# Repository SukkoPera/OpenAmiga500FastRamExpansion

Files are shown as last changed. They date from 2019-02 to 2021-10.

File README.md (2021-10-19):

# OpenAmiga500FastRamExpansion
OpenAmiga500FastRamExpansion is an Open Hardware 4/8 MB Fast RAM Expansion for the Commodore Amiga 500 Computer.

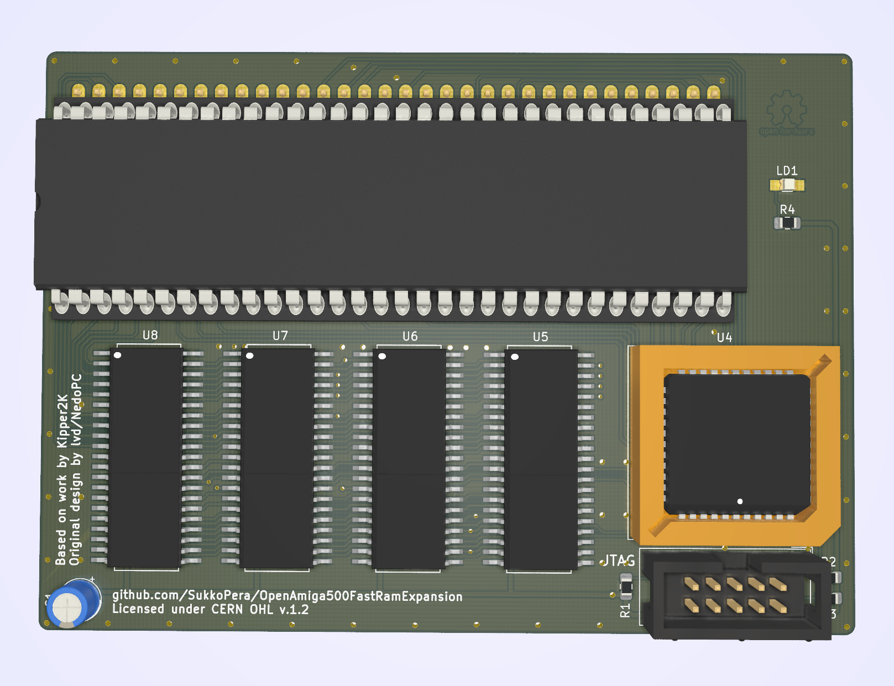
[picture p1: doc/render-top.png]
Board


### Summary
Most low-end Amiga models only came with *Chip RAM*. "Big Box" models allowed for a different type of memory to be installed, known as *Fast RAM*, where *fast* means that it's dedicated to the main processor, so that it doesn't have to compete with the other chips in order to gain access to it (as is the case with Chip RAM). While both Chip and Fast RAM are limited in size, you can have at least a few MB of the latter on all Amigas (usually up to 8), while the former can never exceed 2 MB.

OpenAmiga500FastRamExpansion will allow you to add 4 or 8 MB of Fast RAM to your Amiga 500. This way you will be able to run more applications at once and more quickly. If you combine it with [a chip RAM expansion](http://eab.abime.net/showthread.php?t=85395), you will also be able to run almost all games supported by WHDLoad, pushing your Amiga to its limits.

OpenAmiga500FastRamExpansion is basically a clone of [a RAM expansion produced by Kipper2K a few years ago](http://eab.abime.net/showthread.php?t=64218), based on [an earlier design by lvd/NedoPC](http://lvd.nedopc.com/Projects/a600_8mb/index.html). He has since stopped producing and selling these cards and I thought it was a pity that he didn't open his designs and actually took all of them down, as this card is quite cheap to build and really useful. So I set about recreating it from scratch.

### Memory Compatibility
The required RAM Type is 16 Mbit (1M×16) DRAM in the SOJ-42 package with up to 70-80 ns access time. It is 5v-only DRAM (not SD(!)RAM) often found in old 72-pin SIMMs, EDO chips might work or not. All chips having *8160* in their part number should be OK.

|Model |Maker |Tested |Working |Data Sheet |Notes |
|---|---|:---:|:---:|:---:|---|
|AS4C1M116E5 |Alliance |Yes|Yes| |Tested by @Homer799 |
|GM71C18160 |Hynix/LGS |Yes|Yes|PDF |Tested by lvd in his original project |
|HY5118164B |Hynix |Yes|Yes| |Tested by @Sgw32 |
|KM416C1200AJ |SEC |Yes|Yes| |Reported working by Ronald Baer |
|KM416C1204AJ/BJ|SEC |Yes|Yes|PDF (http://pdf.datasheetcatalog.com/datasheet_pdf/samsung-electronic/KM416C1004BJ-45_to_KM416V1204BT-L7.pdf) |Reported working by screwbreaker |
|MSM5118160 |OKI |Yes|Yes|PDF |Tested by lvd in his original project |
|TMS41860DZ |Texas Instruments |Yes|Yes| |Reported working by Ronald Baer |
|TMS41869DZ |Texas Instruments |No  | | | |
|4218160 |NEC |Yes|Yes| |Reported working by Ronald Baer |
|4218165 |NEC |Yes|Yes|PDF (https://www.datasheetarchive.com/pdf/download.php?id=5f10686e336fc0bb44481c8b0f0340b8d05d8a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) |Tested by SukkoPera |
|VG2618165BJ |Vanguard |Yes|Yes| |Tested by @Csordi |
|NN5118160AJ-60 |NPN |Yes|Yes| |Tested by @RipZ |

RAM chips can either be soldered directly to the board or installed in sockets. While soldering the chips might not be trivial for the unexperienced, sockets for the SOJ-42 package are hard to find and not really easier to solder either, so the choice is up to you.

### Assembly and Installation
Normally it is not necessary to mount all the decoupling capacitors. I usually skip C4, C5, C9, C12, C15 and C18. Maybe C1 can be left out as well if you have a good power supply, your choice. R4 must be chosen according to the particular led you will be using for LD1. Actually you are free to skip LD1 and R4 altogether, if you hate power LEDs.

After everything has been soldered, you will need to program the CPLD. Whenever you do so, **make sure to carefully remove the board from your Amiga, or you might risk damaging it**. You can find the firmware [here](firmware/V2), along with instructions on how to flash it. You can provide power through the pads of C1 if you need to do so.

Make sure to use the [correct firmware version](#Firmware), according to how many chips you soldered on the board! For the 4 MB version, solder U7 and U8 only and use the dedicated firmware.

When assembly is complete, open your A500 and remove the top shield. Carefully remove the CPU (largest chip at bottom left of the board), using a chip extractor or a small flat screwdriver, taking care not to break/bend any pins. Plug it on the board, matching the orientation, and plug the whole board in the CPU socket.

Before reassembling your case, I recommend to run [SysTest/Amiga Test Kit](https://github.com/keirf/Amiga-Stuff). Use the Memory option (<kbd>F1</kbd>), it must show 4/8 MB of Fast RAM. Then start the Memory Test (<kbd>F1</kbd> again) and let it run for 50-100 rounds: if it doesn't find any errors, you are probably good to go. If you get any errors, check your solder joints, starting from actual the RAM chips, as the SOJ package is not very hand-soldering-friendly.

### Firmware
If you are using Kickstart 2.x or higher you should use the latest V2 firmware [here](firmware/V2) noting that it requires an ATF1504AS rather than the older version's ATF1502

If you are using Kickstart 1.3 you will need to use the [V1 Firmware here](firmware/V1)

#### V2 Firmware new features
Thanks to two new features this board is compatible with other autoconfig devices and should no longer cause any conflicts
* Autoconfig snooping - This board will configure itself after every other Autoconfig device
* Autosizing - The firmware will shrink the configured size automatically to make it fit within the remaining free memory pool (8M/4M/2M/1M).

#### V1 Firmware Limitations
The V1 Firmware for OpenAmiga500FastRamExpansion only has a partial implementation of the AutoConfig protocol. This has the following consequences:
- On the A500 it will only work if nothing is connected to the side expansion port (or if whatever is connected does NOT use AutoConfig).
- On the A2000 it will only work if nothing is installed in the Zorro expansion slots (again: or if whatever you installed there does not use AutoConfig).
- On the CDTV it just won't work (since the DMAC uses AutoConfig and is built-in.)

Because of these limitations it is recommended to use the new Firmware where possible, this will allow your board to coexist with other Autoconfig devices.
If you cannot use the V2 firmware for some reason (i.e you use Kickstart 1.3) then the only way to get around these limitations is flashing an alternative firmware on the board which does not use AutoConfig, but then you will have to add the RAM manually in Workbench, using the `addmem` utility. More on this soon.

### License
The OpenAmiga500FastRamExpansion documentation, including the design itself, is copyright &copy; SukkoPera 2019.

OpenAmiga500FastRamExpansion is Open Hardware licensed under the [CERN OHL v. 1.2](http://ohwr.org/cernohl).

You may redistribute and modify this documentation under the terms of the CERN OHL v.1.2. This documentation is distributed *as is* and WITHOUT ANY EXPRESS OR IMPLIED WARRANTIES whatsoever with respect to its functionality, operability or use, including, without limitation, any implied warranties OF MERCHANTABILITY, SATISFACTORY QUALITY, FITNESS FOR A PARTICULAR PURPOSE or infringement. We expressly disclaim any liability whatsoever for any direct, indirect, consequential, incidental or special damages, including, without limitation, lost revenues, lost profits, losses resulting from business interruption or loss of data, regardless of the form of action or legal theory under which the liability may be asserted, even if advised of the possibility or likelihood of such damages.

A copy of the full license is included in file [LICENSE.pdf](LICENSE.pdf), please refer to it for applicable conditions. In order to properly deal with its terms, please see file [LICENSE_HOWTO.pdf](LICENSE_HOWTO.pdf).

The contact points for information about manufactured Products (see section 4.2) are listed in file [PRODUCT.md](PRODUCT.md).

Any modifications made by Licensees (see section 3.4.b) shall be recorded in file [CHANGES.md](CHANGES.md).

The Documentation Location of the original project is https://github.com/SukkoPera/OpenAmiga500FastRamExpansion/.

### Support the Project
Since the project is open you are free to get the PCBs made by your preferred manufacturer, however in case you want to support the development, you can order them from PCBWay through this link:

PCB from PCBWay (https://www.pcbway.com/project/shareproject/OpenAmiga500FastRamExpansion_V1.html)

You get my gratitude and cheap, professionally-made and good quality PCBs, I get some credit that will help with this and [other projects](https://www.pcbway.com/project/member/shareproject/?bmbid=41100). You won't even have to worry about the various PCB options, it's all pre-configured for you!

Also, if you still have to register to that site, [you can use this link](https://www.pcbway.com/setinvite.aspx?inviteid=41100) to get some bonus initial credit (and yield me some more).

Again, if you want to use another manufacturer, feel free to, don't feel obligated :). But then you can buy me a coffee if you want:

<a href='https://ko-fi.com/L3L0U18L' target='_blank'>Buy Me a Coffee at ko-fi.com</a>

### Get Help
If you need help or have questions, you can join [the official Telegram group](https://t.me/joinchat/HUHdWBC9J9JnYIrvTYfZmg).

### Thanks
- lvd for the initial design and the support he gave me during development
- Kipper2K for making his boards
- majinga for helping with the testing

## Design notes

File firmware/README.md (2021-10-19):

# Firmware
Before installing the board into your Amiga, you will need to program the CPLD chip.

The firmware is the same as the original project by lvd. It has been copied here for convenience, but it is unmodified.

The firmware was originally developed for Altera `EPM7032SLC44` CPLDs.

Atmel/Microchip makes compatible devices under the `ATF1502` series, so the `ATF1502AS-10JC44` can be used as an alternative, which is easier to find nowadays (-10J*U*44 is fine as well).

## Flashing the firmware

### Altera EPM7032SLC44/EPM7064SLC44
You will need to load the `.POF` file in `quartus_pgm` and flash it using one of the cheap USB Blaster programmer clones you can find everywhere.

*NOTE: One user recommends NOT to use the auto-detect button as it will add two ICs to the window. Just select the USB Blaster hardware and load the .POF file (make sure to check only Program/Configure + Verify!). Then hit the Start button to flash.*

### Atmel/Microchip ATF1502AS-10JC44/ATF1504AS-10JC44 (Official way)
You can program the .JED file using the [ATDH1150USB](https://www.microchip.com/DevelopmentTools/ProductDetails/ATDH1150USB) programmer.

### Atmel/Microchip ATF1502AS-10JC44/ATF1504AS-10JC44 (Cheaper and hackish way)
These days you will only find the ATF1502AS-10JC44 (or -10JU44) on the market, but, if you read the above, you will know that you will need to buy a >50€ programmer to program it, which doesn't sound reasonable, as this will most likely only need to be done once. Besides, all the tools mentioned above are Windows-only so if you are a Linux user like me, you're pretty screwed. Luckily, there is a solution that allows flashing the Atmel chip with the cheap USB Blaster clones. I have developed and tested it under Linux, but it should also work on Windows and OS X.

First of all you need to power the board. JTAG programmers are not supposed to provide power, hence you need to do so separately. The board does not have a dedicated power connector, but you can use the pads of C1 (which I don't recommend installing, unless you have stability issues) or pins 2 (GND) and 4 (VCC) of the IDC connector. The board needs 5V, I usually take those from an Arduino board but feel free to use whatever suits you.

On the software side, you will need [UrJTAG](http://urjtag.sourceforge.net). I have only tested version 2018.09, others might work or not. I am not sure this version is readily available in binary format, so you might have to compile it from sources.

You will also need to get the [BSDL (Boundary Scan Description Language) files for the 1502 CPLDs](http://ww1.microchip.com/downloads/en/DeviceDoc/1502bsdl.zip). Download the zip file, uncompress it anywhere you like and take note of the path, you will need it later.

Finally, you will need the firmware in SVF format, available in this folder. Use either `4mb.svf` or `8mb.svf` according to how you assembled your board.

Now you are ready for the actual flashing, so connect your USB Blaster to the IDC connector on the board and plug it into an USB port on your PC. Then run urjtag as follows:

```
sukko@shockwave firmware $ sudo jtag

UrJTAG 2018.09 #
Copyright (C) 2002, 2003 ETC s.r.o.
Copyright (C) 2007, 2008, 2009 Kolja Waschk and the respective authors

UrJTAG is free software, covered by the GNU General Public License, and you are
welcome to change it and/or distribute copies of it under certain conditions.
There is absolutely no warranty for UrJTAG.

warning: UrJTAG may damage your hardware!
Type "quit" to exit, "help" for help.

jtag> cable UsbBlaster
Connected to libftdi driver.
```

This means that your USB Blaster was detected correctly. Let's load the BSDL files, this is where you will need to use the path you took note of at the beginning:
```
jtag> bsdl path <path>
jtag>
```

Now we can scan the JTAG chain:
```
jtag> detect
IR length: 10
Chain length: 1
Device Id: 00000001010100000010000000111111 (0x0150203F)
  Filename:     bsdl/1502AS_A44.bsd
```

This means that the CPLD was found and it is ready to be programmed. If you get no output at this step, try disconnecting and reconnecting the USB Blaster or power to the board. If the chip gets detected but it is reported as unsupported, check that you downloaded the correct BSDL files. Then start the flashing:
```
jtag> svf 8mb.svf progress stop
warning: unimplemented mode 'ABSENT' for TRST
detail: Parsing   3660/3668 ( 99%)detail:
detail: Scanned device output matched expected TDO values.
```

If you get the above output, the flashing was successful and you can start using your board. If instead you get something like:
```
jtag> svf 8mb.svf
warning: unimplemented mode 'ABSENT' for TRST
Error svf: mismatch at position 64 for TDO
 in input file between line 2196 col 1 and line 2198 col 32
```

Then there was an error during the flashing, check your wiring, power and try again.

#### USB Blaster Clones
You are recommended to get **a full-size Altera USB Blaster clone**, i.e. one of these:

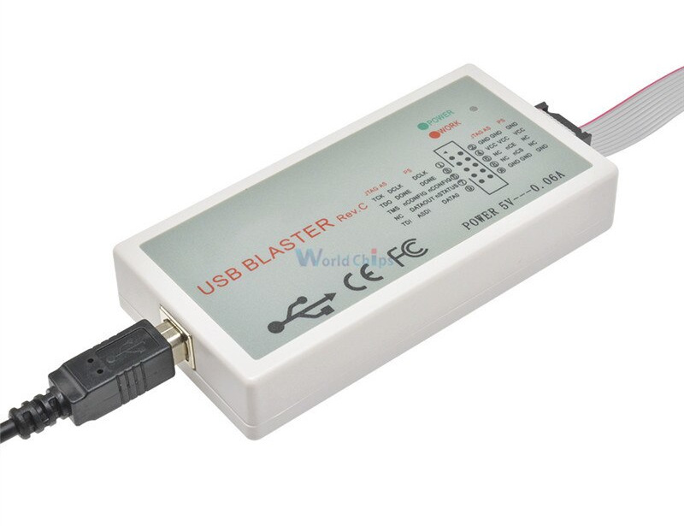
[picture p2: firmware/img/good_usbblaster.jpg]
Full-Size


Note the *Rev.C*: I'm not sure if it is crucial, but the one I have says so and is working very well.

Do **NOT** buy this:

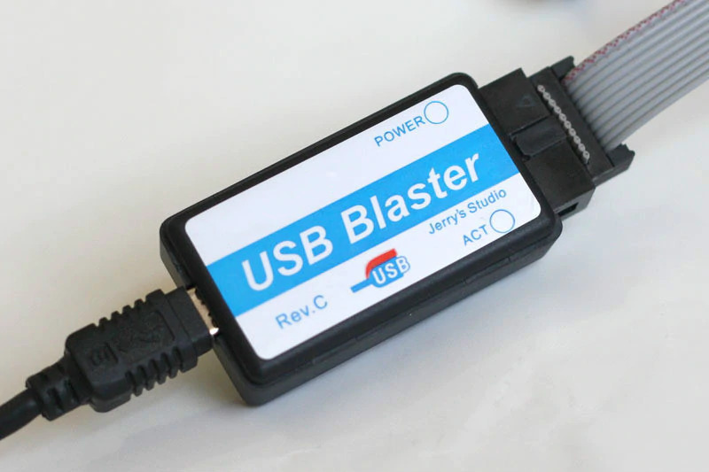
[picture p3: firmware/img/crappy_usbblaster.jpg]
Smaller


It does not work correctly, as it always hangs between 47% and 49% of the flashing process.

### Atmel/Microchip ATF1502AS-10JC44 (Through the Parallel port)

As an alternative, if you have an old computer with LPT1 and some version of Windows, you can build [the cable mentioned here](https://github.com/MattisLind/82S100replacement) and use it with [Microchip's ATMISP tool](https://www.microchip.com/design-centers/programmable-logic/spld-cpld/tools/software/atmisp).

## Windows considerations
I have managed to build a Windows binary of UrJTAG with only the minimum options needed to program these CPLDs through a USB Blaster. It was tested by a couple of users and seemed to be working fine. A user even automated the procedure, so now you can just download [the UrJTAG.zip file from the windows folder](windows/UrJTAG.zip), unzip it and double click on the `runme.bat` script (with the programmer and board already connected to your PC): this should guide you through the whole flashing process.

I hope this works for you, but please note that **it is unsupported**, as I have no computers running Windows.

## Tinkering with the firmware
The firmware was developed with Quartus 7.2, somewhat totally old and outdated, but I never got any problems with it. I DO NOT recommend using Quartus 6.x as I caught it generating wrong designs (in a way, nothing is working and when you swap to Quartus 7.2 not touching you project, everything is working back).

If you want to move to something newer, it seems that Quartus 10.x and 11.x are still supporting EPM7000S chips. Starting from Quartus 12.x there's no more support for that devices.

### POF => JED
Quartus will produce a .POF file. This can be converted to a .JED file for Atmel devices through [Microchip's POF2JED utility](https://www.microchip.com/design-centers/programmable-logic/spld-cpld/tools/software/pof2jed), which is Windows-only unfortunately.

### JED => SVF
An SVF file can be produced using [ATMISP](https://www.microchip.com/design-centers/programmable-logic/spld-cpld/tools/software/atmisp), which is also Windows-only.

### Used chips from China
The chips can be pre-used if you bought your ATF1502AS from China. Sometimes JTAG interface is disabled on them, preventing normal JTAG operations.

To enable JTAG, connect +12V power through a 2.2kOhm resistor to pin 7 on the 68000 CPU connector. Afterwards flash the `atf1502as_erase.svf` file to the CLPD. Then you can follow the normal programming procedures.

## Thanks
- *lvd* for providing most of the above information and helping me come up with the Linux flashing procedure.
- *majinga* and *go0se* for testing and helping improve this procedure.
- EAB forum user *katarakt* for the note on Quartus.
- Szymon Roslowski and Graham P. for testing and improving the Windows package.

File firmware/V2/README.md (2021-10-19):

# GottaGoFast firmware for SukkoPera's OpenAmiga500FastRam expansion

This is a port of the GottaGoFastRAM firmware for the OpenAmiga500FastRam Expansion.  
It adds better Autoconfig support, making the board play nicely with other Autoconfig devices.

## Requirements

* Requires Kickstart 2 or higher.
* This firmware is only compatible with either the ATF1504AS or EPM7064S CPLDs, the ATF1502 specced for this board originally does not have enough resources for this firmware.

## Usage

Follow the programming steps [here](../README.md)

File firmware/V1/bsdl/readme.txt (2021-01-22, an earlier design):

******************************************************************************
*           BSDL files for ATF1502AS/ASL/ASV in all package types            *
******************************************************************************

1502AS_A44.bsd  - BSDL file for ATF1502AS/ASL in 44-pin TQFP package type.

1502AS_J44.bsd  - BSDL file for ATF1502AS/ASL in 44-pin PLCC package type.

1502ASV_A44.bsd - BSDL file for ATF1502ASV in 44-pin TQFP package type.

1502ASV_J44.bsd - BSDL file for ATF1502ASV in 44-pin PLCC package type.

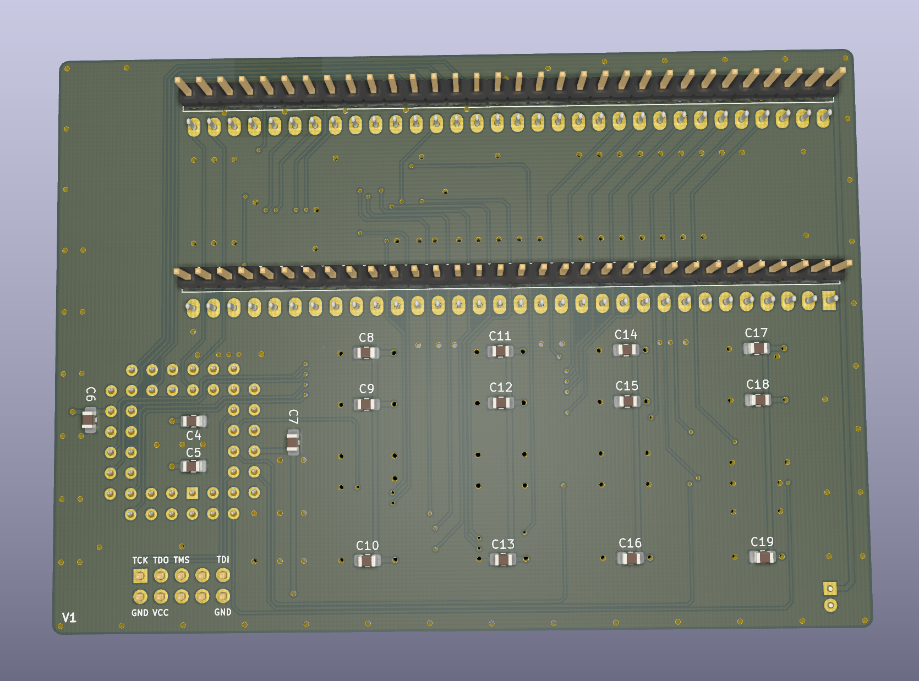
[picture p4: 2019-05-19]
doc/render-bottom.png

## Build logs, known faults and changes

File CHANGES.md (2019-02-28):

## CHANGES

Any modifications to the OpenAmiga500FastRamExpansion design and documentation made by any Licensee MUST be noted in this file, as per *section 3.4.b* of the [license](LICENSE.pdf).

### (Date) - (Author)
(Description)

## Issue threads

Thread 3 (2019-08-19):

Fix skippable cap numbers

SukkoPera, 2019-08-19:
Brought over from A600 expansion, they do not seem correct.

(Thanks @screwbreaker)

SukkoPera, 2019-08-19:
Not applicable.

Closed 2019-08-19.

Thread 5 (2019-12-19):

New memory compatibly testing

Homer799, 2019-12-19:
AS4C1M116E5 - Alliance - confirmed working
IS41C16105 - TBC
GM71C18163 - TBC
TC5118160AJ - TBC

Csordi, 2019-12-28:
I used VG2618165BJ - Vanguard Microelectronics and this RAMs is also working fine.

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

RipZ, 2020-11-15:
NPN NN5118160AJ-60 - Worked
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

Sgw32, 2021-01-10:
HY5118164B from old RAMs - working!

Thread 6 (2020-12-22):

TF534 compatibility.

andreacampanella, 2020-12-22:
I have been using the card for an year and I recently got a TF534. I can see the memory in Workbench but ram test comes back with some errors.

Is there any known problem with it?

It's 8MB

SukkoPera, 2020-12-23:
To be honest, I don't know. I think it is *supposed* to work with the TF534, but I don't have one and can't say for sure.

I'm leaving this open for anyone to contribute.

andreacampanella, 2020-12-24:
I think my board it's defective, I have to investigate more.

This is the error but I can't really understand how to interpret it.
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

SukkoPera, 2020-12-24:
I had lot of similar errors while testing mem68k with my TF530. Never managed to fix them.

I'm sorry but I really can't help more :(.

andreacampanella, 2020-12-25:
Weird, it seems something isolated to the 500+ I'm using, the other 500 it's kinda fine.

Need more testing, seems harware related.

SukkoPera, 2020-12-25:
Maybe a wonky socket?

andreacampanella, 2020-12-25:
I don't really understand, I just removed all the chip ram and I'm about to test it.

andreacampanella, 2021-01-04:
yeah, something is up with my 500+, works with my 500.

SukkoPera, 2021-01-04:
OK, closing then.

Closed 2021-01-04.

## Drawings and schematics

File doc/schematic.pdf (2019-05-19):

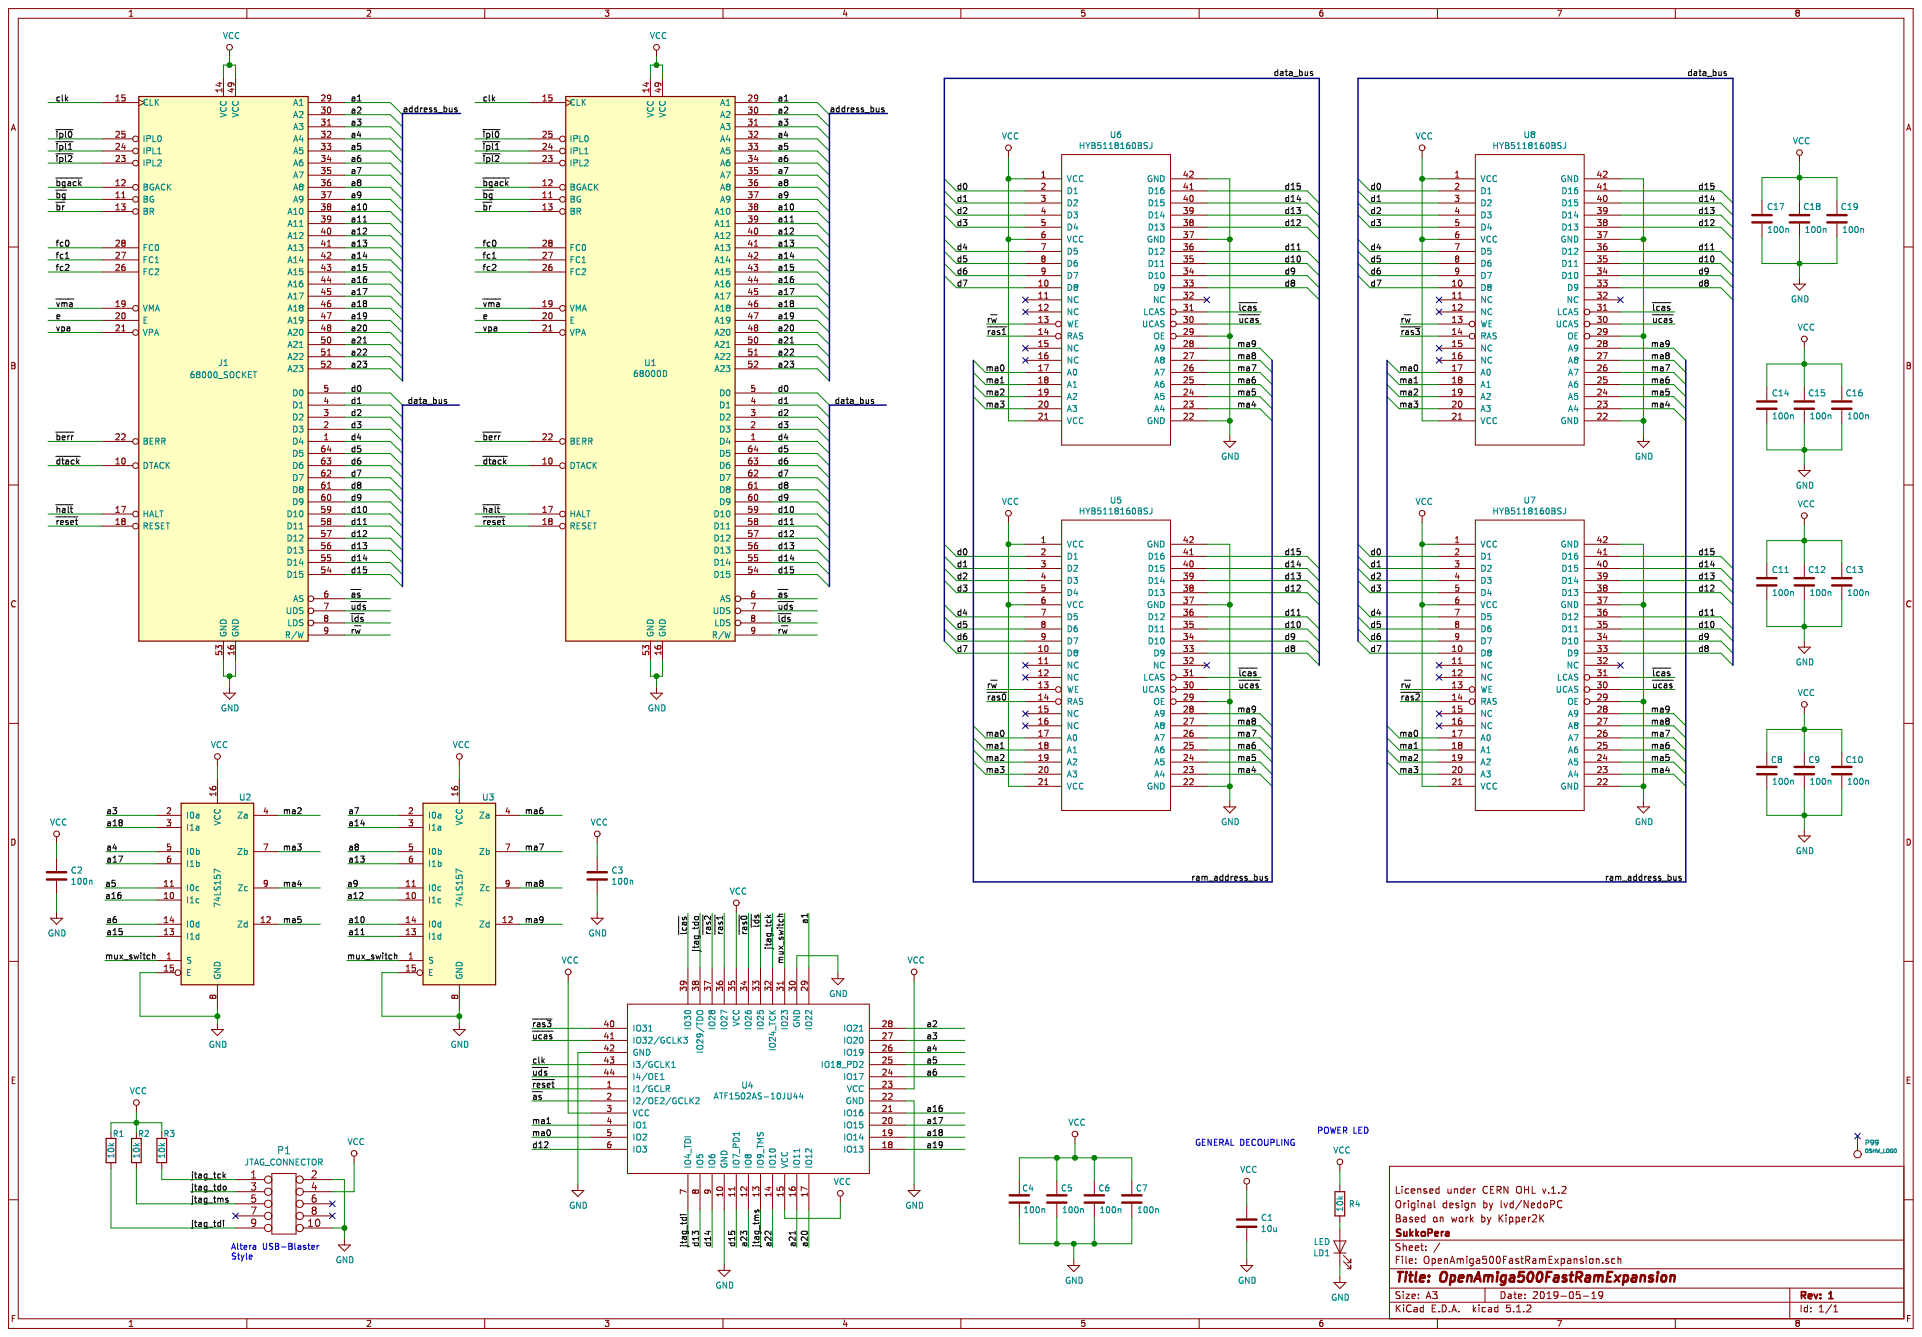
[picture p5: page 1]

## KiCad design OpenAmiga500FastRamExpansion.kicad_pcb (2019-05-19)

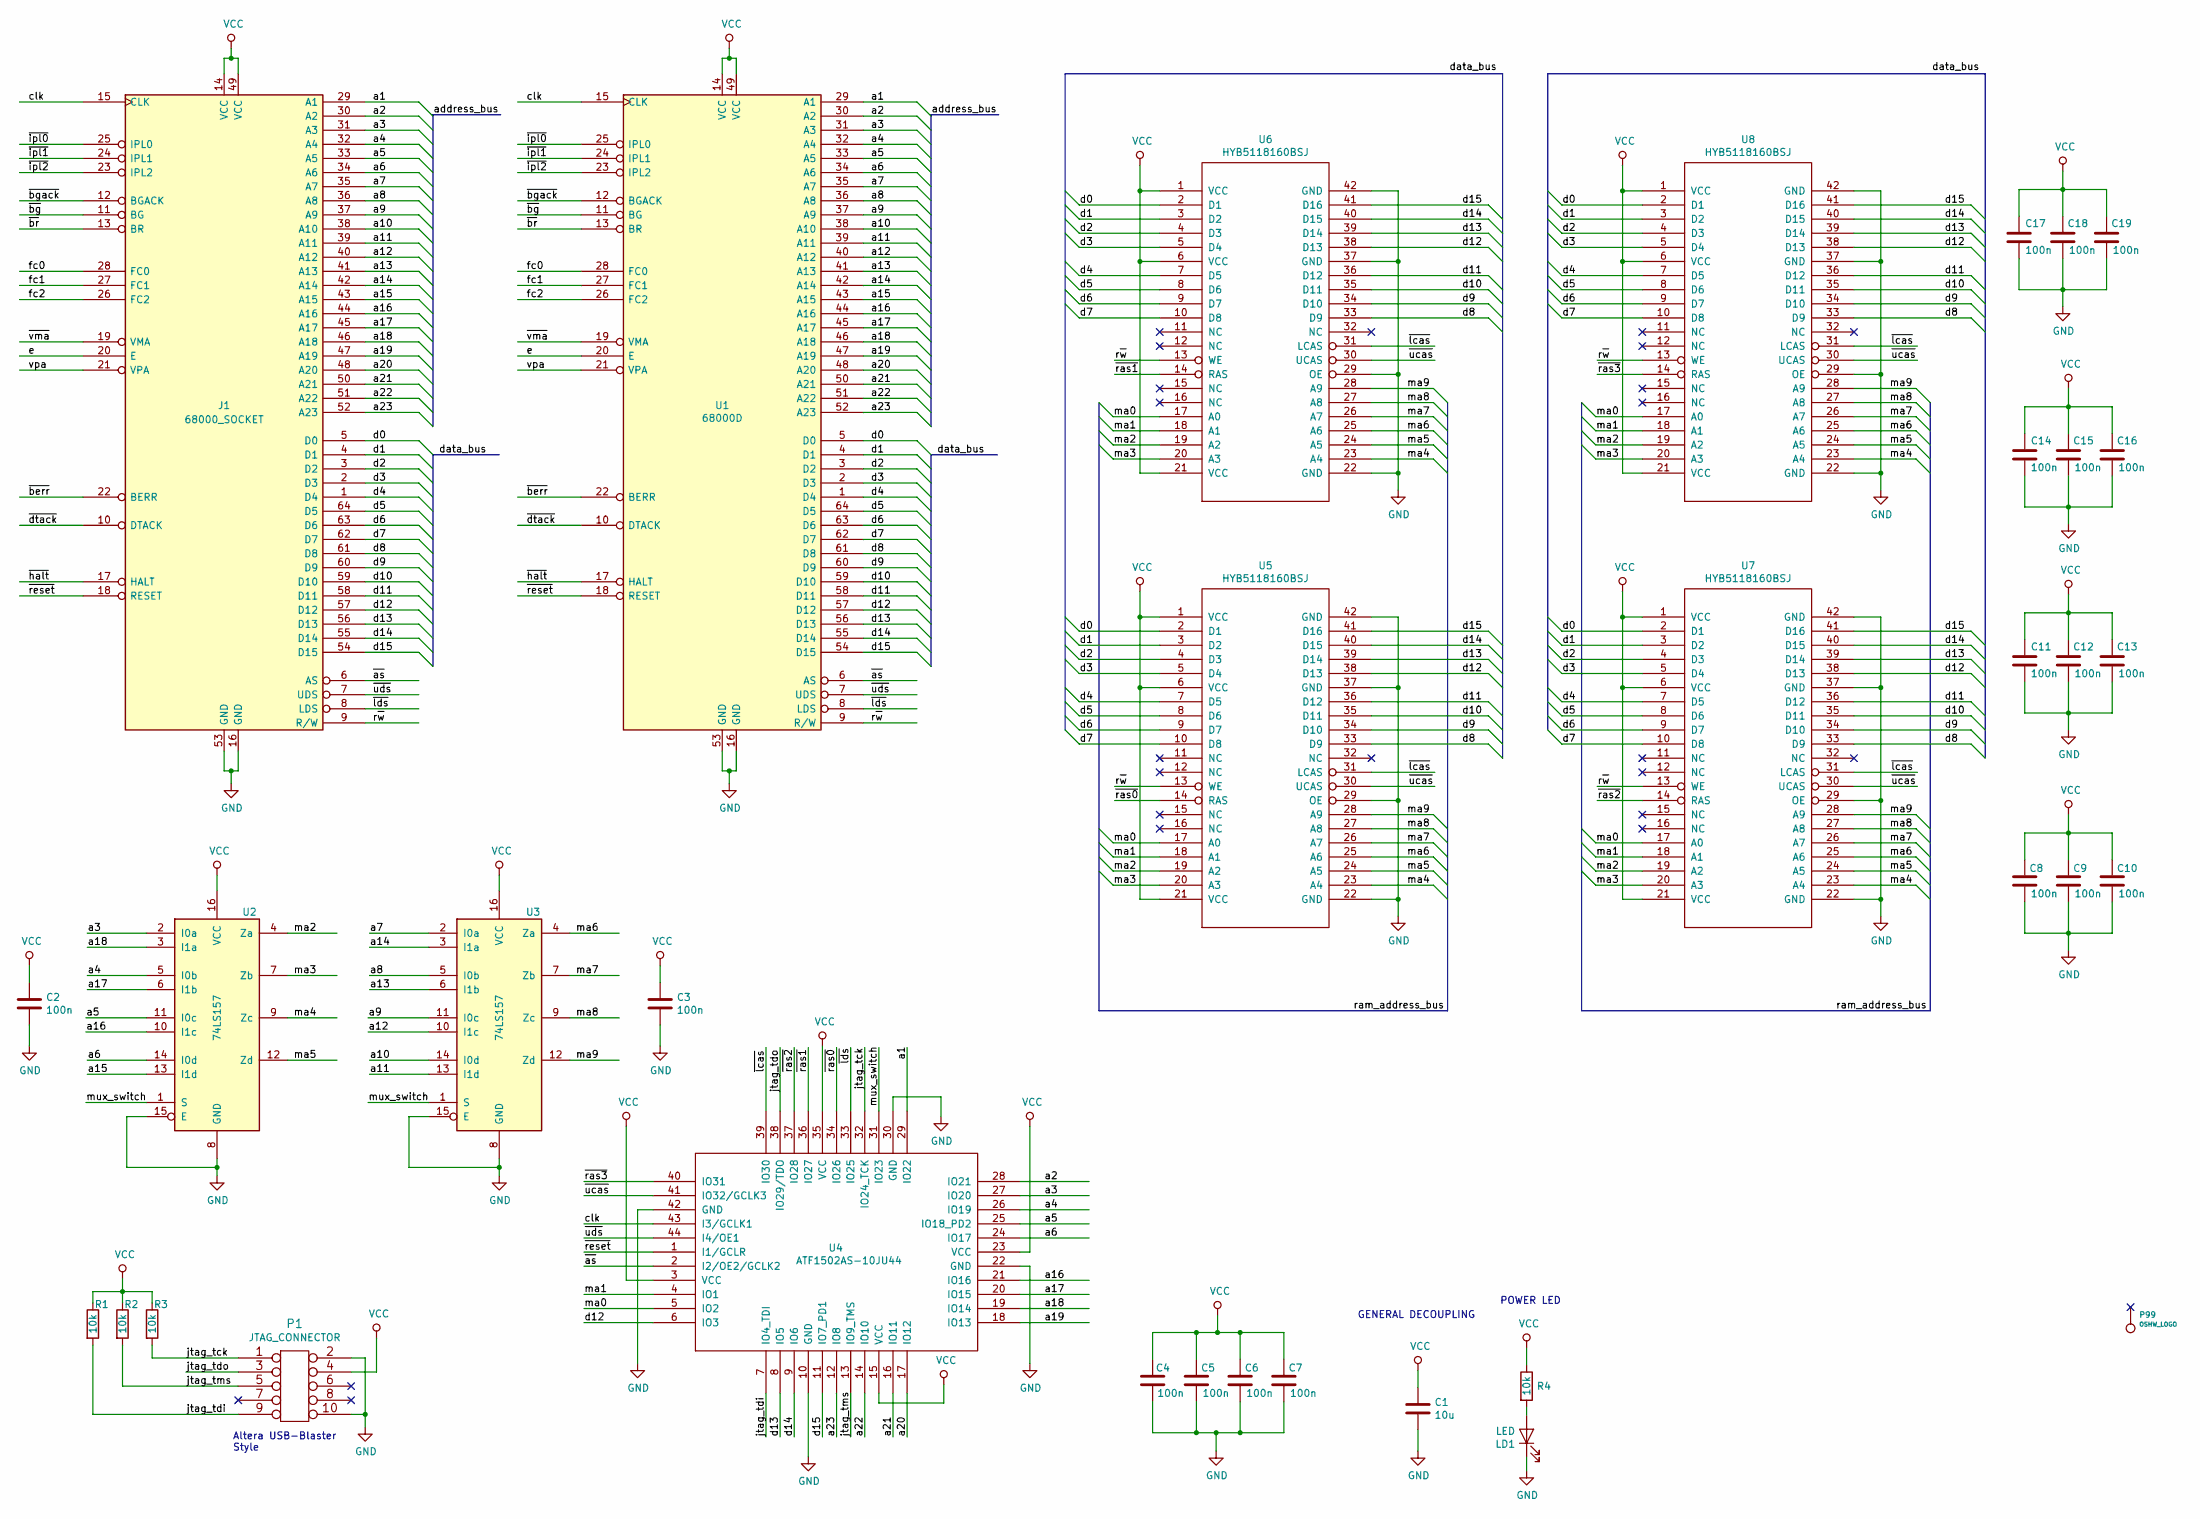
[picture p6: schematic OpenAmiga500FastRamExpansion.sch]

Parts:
C1: 10u; CP_Radial_D5.0mm_P2.00mm
C2, C3, C4, C5, C6, C7, C8, C9, C10, C11, C12, C13, C14, C15, C16, C17, C18, C19: 100n; C_0805_2012Metric_Pad1.15x1.40mm_HandSolder
J1: 68000_SOCKET; DIP-64_W22.86mm_Socket_LongPads_Socket
LD1: LED; LED_0805_HandSoldering_ModSilkS
P1: JTAG_CONNECTOR; IDC-Header_2x05_P2.54mm_Vertical
P99: OSHW_LOGO; OSHW-Logo2_7.3x6mm_Copper
R1, R2, R3, R4: 10k; R_0805_2012Metric_Pad1.15x1.40mm_HandSolder
U1: 68000D; DIP-64_W22.86mm_Socket_LongPads_IC
U2, U3: 74LS157; SOIC-16_3.9x9.9mm_P1.27mm
U4: ATF1502AS-10JU44; PLCC-44_THT-Socket
U5, U6, U7, U8: HYB5118160BSJ; SOJ-42-LongPads

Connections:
/a1: J1.29 (A1), U1.29 (A1), U4.29 (IO22)
/a2: J1.30 (A2), U1.30 (A2), U4.28 (IO21)
/a3: J1.31 (A3), U1.31 (A3), U2.2 (I0a), U4.27 (IO20)
/a4: J1.32 (A4), U1.32 (A4), U2.5 (I0b), U4.26 (IO19)
/a5: J1.33 (A5), U1.33 (A5), U2.11 (I0c), U4.25 (IO18_PD2)
/a6: J1.34 (A6), U1.34 (A6), U2.14 (I0d), U4.24 (IO17)
/a7: J1.35 (A7), U1.35 (A7), U3.2 (I0a)
/a8: J1.36 (A8), U1.36 (A8), U3.5 (I0b)
/a9: J1.37 (A9), U1.37 (A9), U3.11 (I0c)
/a10: J1.38 (A10), U1.38 (A10), U3.14 (I0d)
/a11: J1.39 (A11), U1.39 (A11), U3.13 (I1d)
/a12: J1.40 (A12), U1.40 (A12), U3.10 (I1c)
/a13: J1.41 (A13), U1.41 (A13), U3.6 (I1b)
/a14: J1.42 (A14), U1.42 (A14), U3.3 (I1a)
/a15: J1.43 (A15), U1.43 (A15), U2.13 (I1d)
/a16: J1.44 (A16), U1.44 (A16), U2.10 (I1c), U4.21 (IO16)
/a17: J1.45 (A17), U1.45 (A17), U2.6 (I1b), U4.20 (IO15)
/a18: J1.46 (A18), U1.46 (A18), U2.3 (I1a), U4.19 (IO14)
/a19: J1.47 (A19), U1.47 (A19), U4.18 (IO13)
/a20: J1.48 (A20), U1.48 (A20), U4.17 (IO12)
/a21: J1.50 (A21), U1.50 (A21), U4.16 (IO11)
/a22: J1.51 (A22), U1.51 (A22), U4.14 (IO10)
/a23: J1.52 (A23), U1.52 (A23), U4.12 (IO8)
/clk: J1.15 (CLK), U1.15 (CLK), U4.43 (I3/GCLK1)
/d0: J1.5 (D0), U1.5 (D0), U5.2 (D1), U6.2 (D1), U7.2 (D1), U8.2 (D1)
/d1: J1.4 (D1), U1.4 (D1), U5.3 (D2), U6.3 (D2), U7.3 (D2), U8.3 (D2)
/d2: J1.3 (D2), U1.3 (D2), U5.4 (D3), U6.4 (D3), U7.4 (D3), U8.4 (D3)
/d3: J1.2 (D3), U1.2 (D3), U5.5 (D4), U6.5 (D4), U7.5 (D4), U8.5 (D4)
/d4: J1.1 (D4), U1.1 (D4), U5.7 (D5), U6.7 (D5), U7.7 (D5), U8.7 (D5)
/d5: J1.64 (D5), U1.64 (D5), U5.8 (D6), U6.8 (D6), U7.8 (D6), U8.8 (D6)
/d6: J1.63 (D6), U1.63 (D6), U5.9 (D7), U6.9 (D7), U7.9 (D7), U8.9 (D7)
/d7: J1.62 (D7), U1.62 (D7), U5.10 (D8), U6.10 (D8), U7.10 (D8), U8.10 (D8)
/d8: J1.61 (D8), U1.61 (D8), U5.33 (D9), U6.33 (D9), U7.33 (D9), U8.33 (D9)
/d9: J1.60 (D9), U1.60 (D9), U5.34 (D10), U6.34 (D10), U7.34 (D10), U8.34 (D10)
/d10: J1.59 (D10), U1.59 (D10), U5.35 (D11), U6.35 (D11), U7.35 (D11), U8.35 (D11)
/d11: J1.58 (D11), U1.58 (D11), U5.36 (D12), U6.36 (D12), U7.36 (D12), U8.36 (D12)
/d12: J1.57 (D12), U1.57 (D12), U4.6 (IO3), U5.38 (D13), U6.38 (D13), U7.38 (D13), U8.38 (D13)
/d13: J1.56 (D13), U1.56 (D13), U4.8 (IO5), U5.39 (D14), U6.39 (D14), U7.39 (D14), U8.39 (D14)
/d14: J1.55 (D14), U1.55 (D14), U4.9 (IO6), U5.40 (D15), U6.40 (D15), U7.40 (D15), U8.40 (D15)
/d15: J1.54 (D15), U1.54 (D15), U4.11 (IO7_PD1), U5.41 (D16), U6.41 (D16), U7.41 (D16), U8.41 (D16)
/e: J1.20 (E), U1.20 (E)
/fc0: J1.28 (FC0), U1.28 (FC0)
/fc1: J1.27 (FC1), U1.27 (FC1)
/fc2: J1.26 (FC2), U1.26 (FC2)
/jtag_tck: P1.1, R3.2, U4.32 (IO24_TCK)
/jtag_tdi: P1.9, R1.2, U4.7 (IO4_TDI)
/jtag_tdo: P1.3, U4.38 (IO29/TDO)
/jtag_tms: P1.5, R2.2, U4.13 (IO9_TMS)
/ma0: U4.5 (IO2), U5.17 (A0), U6.17 (A0), U7.17 (A0), U8.17 (A0)
/ma1: U4.4 (IO1), U5.18 (A1), U6.18 (A1), U7.18 (A1), U8.18 (A1)
/ma2: U2.4 (Za), U5.19 (A2), U6.19 (A2), U7.19 (A2), U8.19 (A2)
/ma3: U2.7 (Zb), U5.20 (A3), U6.20 (A3), U7.20 (A3), U8.20 (A3)
/ma4: U2.9 (Zc), U5.23 (A4), U6.23 (A4), U7.23 (A4), U8.23 (A4)
/ma5: U2.12 (Zd), U5.24 (A5), U6.24 (A5), U7.24 (A5), U8.24 (A5)
/ma6: U3.4 (Za), U5.25 (A6), U6.25 (A6), U7.25 (A6), U8.25 (A6)
/ma7: U3.7 (Zb), U5.26 (A7), U6.26 (A7), U7.26 (A7), U8.26 (A7)
/ma8: U3.9 (Zc), U5.27 (A8), U6.27 (A8), U7.27 (A8), U8.27 (A8)
/ma9: U3.12 (Zd), U5.28 (A9), U6.28 (A9), U7.28 (A9), U8.28 (A9)
/mux_switch: U2.1 (S), U3.1 (S), U4.31 (IO23)
/r~w: J1.9 (R/W), U1.9 (R/W), U5.13 (WE), U6.13 (WE), U7.13 (WE), U8.13 (WE)
/vpa: J1.21 (VPA), U1.21 (VPA)
/~as: J1.6 (AS), U1.6 (AS), U4.2 (I2/OE2/GCLK2)
/~berr: J1.22 (BERR), U1.22 (BERR)
/~bg: J1.11 (BG), U1.11 (BG)
/~bgack: J1.12 (BGACK), U1.12 (BGACK)
/~br: J1.13 (BR), U1.13 (BR)
/~dtack: J1.10 (DTACK), U1.10 (DTACK)
/~halt: J1.17 (HALT), U1.17 (HALT)
/~ipl0: J1.25 (IPL0), U1.25 (IPL0)
/~ipl1: J1.24 (IPL1), U1.24 (IPL1)
/~ipl2: J1.23 (IPL2), U1.23 (IPL2)
/~lcas: U4.39 (IO30), U5.31 (LCAS), U6.31 (LCAS), U7.31 (LCAS), U8.31 (LCAS)
/~lds: J1.8 (LDS), U1.8 (LDS), U4.33 (IO25)
/~ras0: U4.34 (IO26), U5.14 (RAS)
/~ras1: U4.36 (IO27), U6.14 (RAS)
/~ras2: U4.37 (IO28), U7.14 (RAS)
/~ras3: U4.40 (IO31), U8.14 (RAS)
/~reset: J1.18 (RESET), U1.18 (RESET), U4.1 (I1/GCLR)
/~ucas: U4.41 (IO32/GCLK3), U5.30 (UCAS), U6.30 (UCAS), U7.30 (UCAS), U8.30 (UCAS)
/~uds: J1.7 (UDS), U1.7 (UDS), U4.44 (I4/OE1)
/~vma: J1.19 (VMA), U1.19 (VMA)
GND: C1.2, C2.2, C3.2, C4.2, C5.2, C6.2, C7.2, C8.2, C9.2, C10.2, C11.2, C12.2, C13.2, C14.2, C15.2, C16.2, C17.2, C18.2, C19.2, J1.16 (GND), J1.53 (GND), LD1.1 (K), P1.2, P1.10, U1.16 (GND), U1.53 (GND), U2.8 (GND), U2.15 (E), U3.8 (GND), U3.15 (E), U4.10 (GND), U4.22 (GND), U4.30 (GND), U4.42 (GND), U5.22 (GND), U5.29 (OE), U5.37 (GND), U5.42 (GND), U6.22 (GND), U6.29 (OE), U6.37 (GND), U6.42 (GND), U7.22 (GND), U7.29 (OE), U7.37 (GND), U7.42 (GND), U8.22 (GND), U8.29 (OE), U8.37 (GND), U8.42 (GND)
unnamed: LD1.2 (A), R4.2
VCC: C1.1, C2.1, C3.1, C4.1, C5.1, C6.1, C7.1, C8.1, C9.1, C10.1, C11.1, C12.1, C13.1, C14.1, C15.1, C16.1, C17.1, C18.1, C19.1, J1.14 (VCC), J1.49 (VCC), P1.4, R1.1, R2.1, R3.1, R4.1, U1.14 (VCC), U1.49 (VCC), U2.16 (VCC), U3.16 (VCC), U4.3 (VCC), U4.15 (VCC), U4.23 (VCC), U4.35 (VCC), U5.1 (VCC), U5.6 (VCC), U5.21 (VCC), U6.1 (VCC), U6.6 (VCC), U6.21 (VCC), U7.1 (VCC), U7.6 (VCC), U7.21 (VCC), U8.1 (VCC), U8.6 (VCC), U8.21 (VCC)

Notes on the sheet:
Altera USB-Blaster Style
GENERAL DECOUPLING
POWER LED

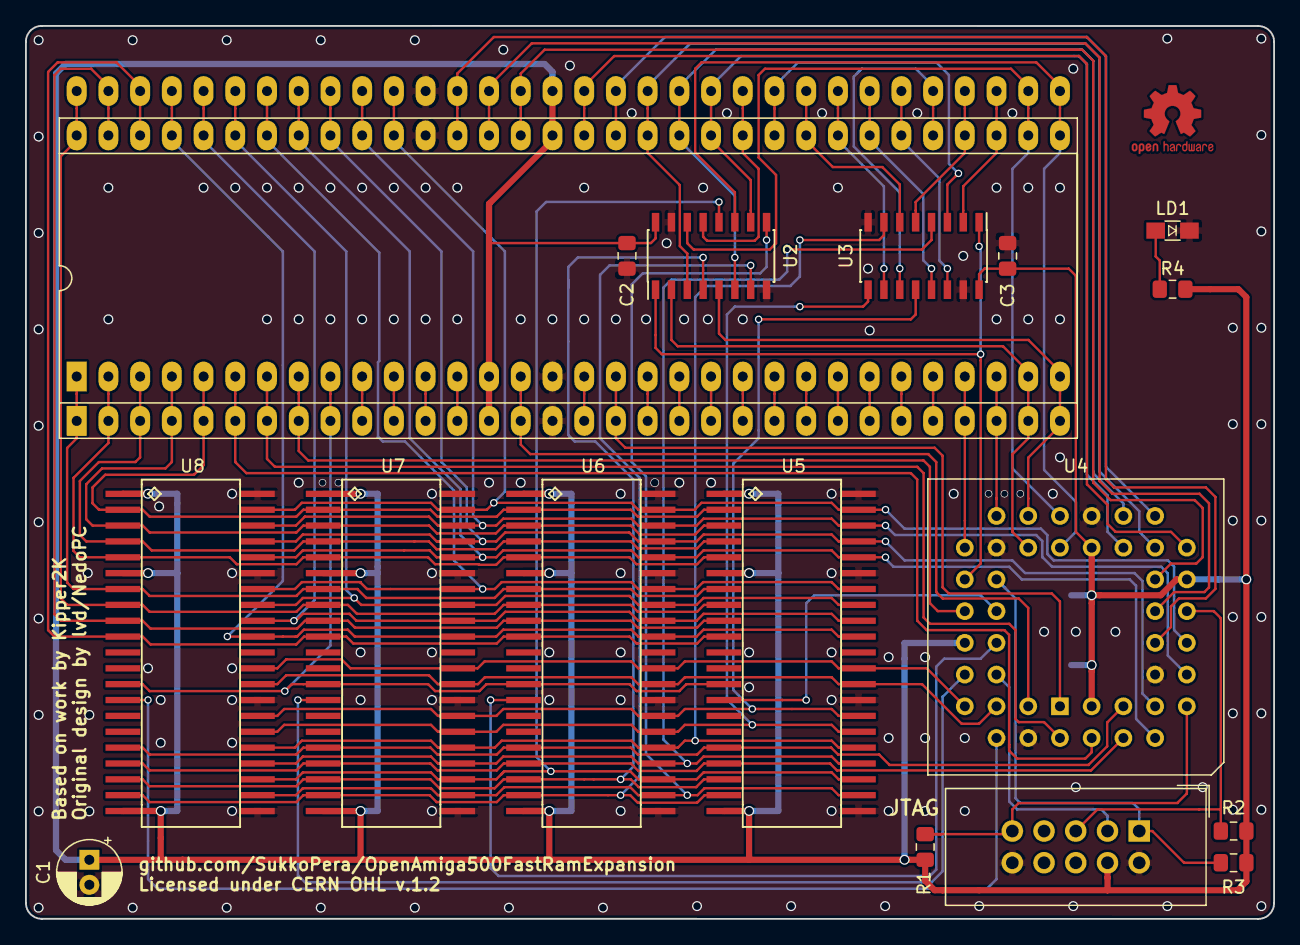
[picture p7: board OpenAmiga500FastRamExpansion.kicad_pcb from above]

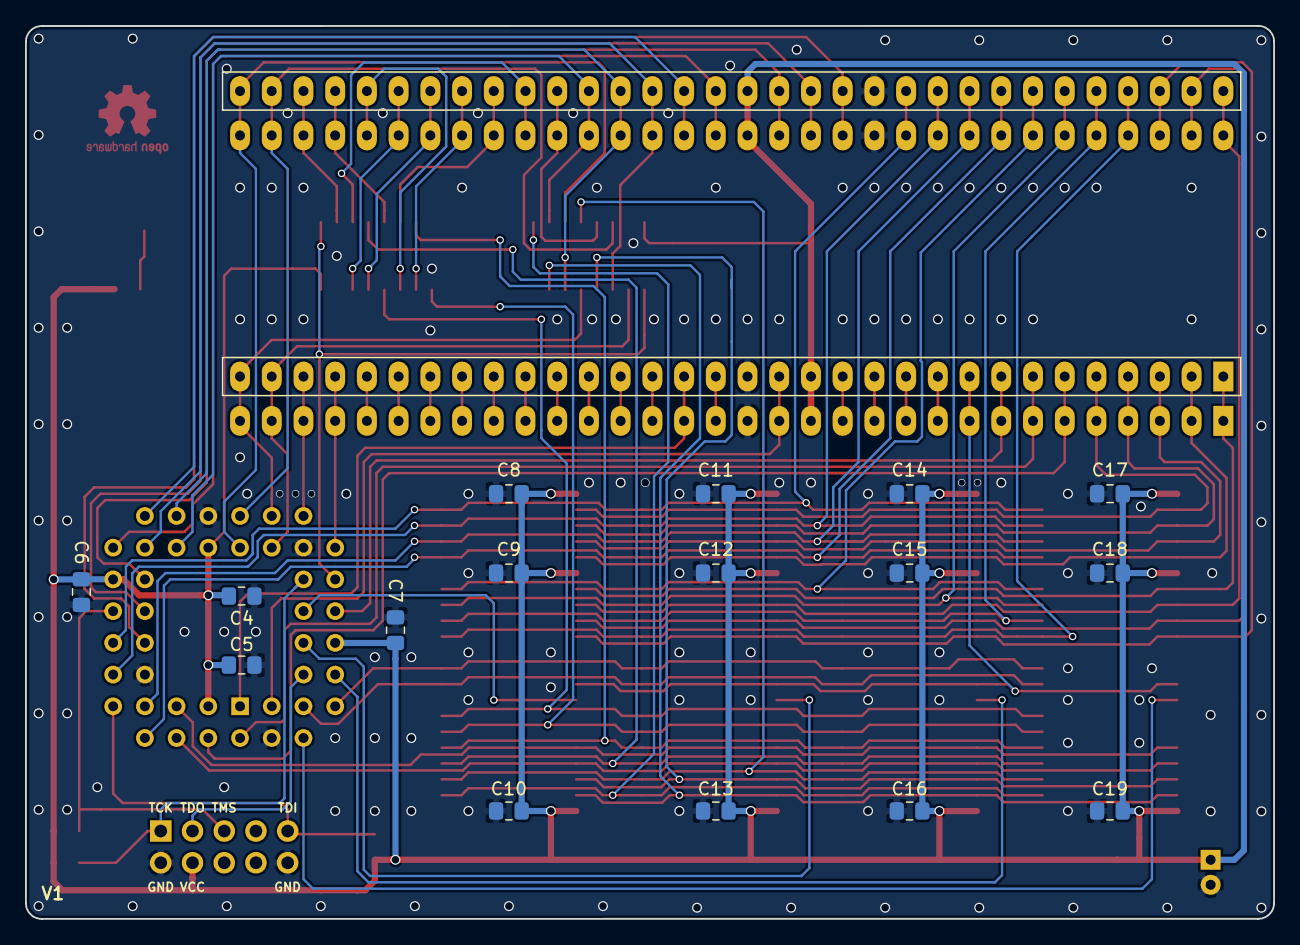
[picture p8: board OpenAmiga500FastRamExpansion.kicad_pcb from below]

Board: 2 copper layers, 100.0 x 71.5 mm, 35 parts (16 on the bottom side), 84 nets.

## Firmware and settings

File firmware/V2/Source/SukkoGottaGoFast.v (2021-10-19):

/*
GottaGoFast FW for SukkoPera's OpenAmiga500FastRamExpansion
Copyright 2021 Matthew Harlum

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
*/

// Config defines
`define autoconfig     // If disabled RAM is always mapped to $200000-9FFFFF
//`define cdtv         // Uncomment to build CDTV compatible version
//`define Size_4MB     // 4MB Maximum, Only uses memory chips U7 & U8

module SukkoGottaGoFast(
    input CLK,
    input RESETn,
    input UDSn,
    input LDSn,
    input ASn,
    inout [15:12] DBUS,
    input [23:16] ADDR_HI,
    input [6:1]   ADDR_LO,
    output reg mux_switch,
    output RAS0n,
    output RAS1n,
    output RAS2n,
    output RAS3n,
    output UCASn,
    output LCASn,
    output reg MA0,
    output reg MA1
    );

// Memory controller

reg ram_cycle;
reg access_ras;
reg access_ucas;
reg access_lcas;
reg refresh_ras;
reg refresh_cas;
reg [7:0] addr_match;
reg AS_last;
reg RWn;

`ifdef autoconfig
// Autoconfig
localparam [15:0] mfg_id  = 16'h07DB;
localparam [7:0]  prod_id = 8'd03;
localparam [15:0] serial  = 16'd420;

localparam Offer_Block1 = 3'b000,
           Offer_Block2 = 3'b001,
           Offer_Block3 = 3'b010,
           Offer_Block4 = 3'b011,
           SHUTUP       = 3'b100;

wire autoconfig_cycle;
reg shutup = 0;
reg configured;
reg [3:0] data_out;

// Autoconfig bus snooping
//
// For some reason Kickstart 2 and up scan the chain multiple times
// Thanks to this we can snoop on autoconfig cycles and then speak up once
// every other board is done being configured.
// No CFGIN connection needed!
reg [3:0] mfg_bad;
reg snoop_cfg;
reg snoop_cfg_next;
reg [3:0] board_reg00;
reg [3:0] board_reg01;
reg [3:0] snooped_autoconfig_state;
reg autoconfig_setup;
reg [3:0] dbus_latched;
reg CFGOUTn;

always @(posedge CLK)
begin
  dbus_latched <= DBUS[15:12];
end

always @(posedge UDSn or negedge RESETn)
begin
  if (!RESETn) begin
    snoop_cfg_next <= 1'b0;
    snoop_cfg <= 1'b0;
    mfg_bad <= 'b0;
    snooped_autoconfig_state <= Offer_Block1;
  end else if (ADDR_HI[23:16] == 8'hE8 & RWn) begin
    case (ADDR_LO[6:1])
    // Chain snooping
    //
    // If Reserved byte is not $F or manufacturer id is $FFFF then no board is answering
    // Once this happens we can set ourselves up to talk to the next autoconfig query


    // Sniff board configuration sizes so we can shrink our offering appropriately
    'h00>>1:
     board_reg00 <= dbus_latched;
    'h02>>1:
     board_reg01 <= dbus_latched;

    'h0C>>1:
      if (!(dbus_latched == 4'hF)) begin // Reserved byte - Should be $FF
        snoop_cfg_next <= 1;
      end
    'h10>>1:
      if (dbus_latched == 4'hF) begin // Manufacturer ID - Should not be $FFFF
        mfg_bad[3] <= 1;
      end
    'h12>>1:
      if (dbus_latched == 4'hF) begin // Manufacturer ID - Should not be $FFFF
        mfg_bad[2] <= 1;
      end
    'h14>>1:
      if (dbus_latched == 4'hF) begin // Manufacturer ID - Should not be $FFFF
        mfg_bad[1] <= 1;
      end
    'h16>>1:
      if (dbus_latched == 4'hF) begin // Manufacturer ID - Should not be $FFFF
        mfg_bad[0] <= 1;
      end
    'h3C>>1:
      if (snoop_cfg_next == 1) begin
       snoop_cfg <= 1;
      end else if (mfg_bad[3:0] == 4'b1111) begin
       snoop_cfg <= 1;
      end
    endcase
  end else if (ADDR_HI[23:16] == 8'hE8 & !RWn & !snoop_cfg) begin
    // The other board is now being given it's address
    // Adjust our offering appropriately
    if (ADDR_LO[6:1] == 'h48>>1) begin
      if (board_reg00[3:2] == 2'b11) begin
        case (board_reg01[2:0])
          3'b000: // 8MB
          snooped_autoconfig_state <= SHUTUP;
         3'b100, 3'b101, 3'b110: // 512k/1/2MB
           if (snooped_autoconfig_state < SHUTUP) begin
            snooped_autoconfig_state <= snooped_autoconfig_state + 1;
           end
         3'b111: // 4MB
           if (snooped_autoconfig_state < Offer_Block3) begin
            snooped_autoconfig_state <= snooped_autoconfig_state + 2;
           end else begin
            snooped_autoconfig_state <= SHUTUP;
           end
        endcase
      end
    end
  end
end

reg [2:0] autoconfig_state;

assign DBUS[15:12] = (autoconfig_cycle & RWn & !ASn & !UDSn) ? data_out[3:0] : 4'bZ;

assign autoconfig_cycle = (ADDR_HI[23:16] == 8'hE8) & snoop_cfg & CFGOUTn;

// Register Config in/out at end of bus cycle
always @(posedge ASn or negedge RESETn)
begin
  if (!RESETn) begin
    CFGOUTn <= 1'b1;
  end else begin
    CFGOUTn <= !shutup;
  end
end

// Offer up to 8MB in 2MB Blocks
always @(posedge CLK or negedge RESETn)
begin
  if (!RESETn) begin
    data_out <= 'bZ;
  end else if (autoconfig_cycle & RWn) begin
    case (ADDR_LO[6:1])      
      'h00:   data_out <= 4'b1110;
      'h01:   data_out <= 4'b0110;
      'h02:   data_out <= ~prod_id[7:4]; // Product number
      'h03:   data_out <= ~prod_id[3:0]; // Product number
      'h04:   data_out <= ~4'b1000;
      'h05:   data_out <= ~4'b0000;
      'h08:   data_out <= ~mfg_id[15:12]; // Manufacturer ID
      'h09:   data_out <= ~mfg_id[11:8];  // Manufacturer ID
      'h0A:   data_out <= ~mfg_id[7:4];   // Manufacturer ID
      'h0B:   data_out <= ~mfg_id[3:0];   // Manufacturer ID
      'h10:   data_out <= ~serial[15:12]; // Serial number
      'h11:   data_out <= ~serial[11:8];  // Serial number
      'h12:   data_out <= ~serial[7:4];   // Serial number
      'h13:   data_out <= ~serial[3:0];   // Serial number
      'h20:   data_out <= 4'b0;
      'h21:   data_out <= 4'b0;
      default: data_out <= 4'hF;
    endcase
  end
end

always @(negedge UDSn or negedge RESETn)
begin
  if (!RESETn) begin
    configured       <= 1'b0;
    shutup           <= 1'b0;
    addr_match       <= 8'b00000000;
    autoconfig_state <= Offer_Block1;
    autoconfig_setup <= 1'b0;
  end else if (autoconfig_setup == 0 & snoop_cfg == 1) begin
    autoconfig_state <= snooped_autoconfig_state;
    autoconfig_setup <= 1;
    if (snooped_autoconfig_state == SHUTUP) begin
      shutup <= 1;
    end
  end else if (autoconfig_cycle & !ASn & !RWn) begin
    if (ADDR_LO[6:1] == 'h26) begin
      // Shutup register
      shutup <= 1;
    end
    else if (ADDR_LO[6:1] == 'h24) begin
      // Configure Address Register
      begin
        case(DBUS)
          4'h2:    addr_match <= (addr_match|8'b00000011);
          4'h4:    addr_match <= (addr_match|8'b00001100);
          4'h6:    addr_match <= (addr_match|8'b00110000);
          4'h8:    addr_match <= (addr_match|8'b11000000);
        endcase
        if (autoconfig_state < Offer_Block4) begin
          autoconfig_state <= autoconfig_state + 1;
        end else begin
          shutup <= 1;
        end
      end
      configured <= 1'b1;
    end
  end
end
`endif
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

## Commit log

2019-02-28 Initial commit, schematic should be OK, PCB routing started
    [OpenAmiga500FastRamExpansion.kicad_pcb, OpenAmiga500FastRamExpansion.sch]
2019-03-01 Completed routing of data bus from CPU to RAM
    [OpenAmiga500FastRamExpansion.kicad_pcb]
2019-03-02 Almost there...
    [OpenAmiga500FastRamExpansion.kicad_pcb]
2019-03-02 Routing complete Ground stitching and some refinements TBD
    [OpenAmiga500FastRamExpansion.kicad_pcb, OpenAmiga500FastRamExpansion.sch]
2019-03-02 Refinements here and there
    [OpenAmiga500FastRamExpansion.kicad_pcb]
2019-03-02 Stitched perimeter and more refinements
    [OpenAmiga500FastRamExpansion.kicad_pcb]
2019-03-03 More and more and more and more and more refinements...
    [OpenAmiga500FastRamExpansion.kicad_pcb]
2019-03-03 Add JTAG connector pinout
    [OpenAmiga500FastRamExpansion.kicad_pcb]
2019-03-03 Ready for prototypes
    [OpenAmiga500FastRamExpansion.kicad_pcb]
2019-03-03 Add missing footprint
2019-03-03 Just can't get enough of vias
    [OpenAmiga500FastRamExpansion.kicad_pcb]
2019-03-03 Remove old pin names
    [OpenAmiga500FastRamExpansion.kicad_pcb]
2019-05-19 Update to KiCad 5.1.2
    [OpenAmiga500FastRamExpansion.kicad_pcb, OpenAmiga500FastRamExpansion.sch]
2019-05-19 Fix #1 and we're ready for V1
    [OpenAmiga500FastRamExpansion.kicad_pcb, OpenAmiga500FastRamExpansion.sch]
2021-06-15 Fixup AutoSnoop for KS 3.1.4/3x0/3.2
    [SukkoGottaGoFast.v]

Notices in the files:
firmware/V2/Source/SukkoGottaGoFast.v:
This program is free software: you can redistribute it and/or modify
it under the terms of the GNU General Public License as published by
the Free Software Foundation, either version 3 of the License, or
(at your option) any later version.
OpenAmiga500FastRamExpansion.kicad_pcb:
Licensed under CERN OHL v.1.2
